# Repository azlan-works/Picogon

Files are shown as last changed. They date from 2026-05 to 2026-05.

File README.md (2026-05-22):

# Picogon
The Picogon in an opensource RP2354A based board for compact embedded applications. Designed as a host platform to integrate with more complex use cases, with peripherals attachable via exposed ENIG pads that connect to spring contacts on a compatible daughterboard. 

## Features:

- USB-C PD/PPS (3.3V to 24V)
- Battery management (3.7V LiPo)
- WiFi/BLE (2.4GHz built-in antenna)
- LoRa (SX1262 868-915MHz UFL connector)
- 9-axis DoF (IMU + Magnetometer)
- QWIIC/Stemma I2C port

  

  ## Notes:
  Currently untested

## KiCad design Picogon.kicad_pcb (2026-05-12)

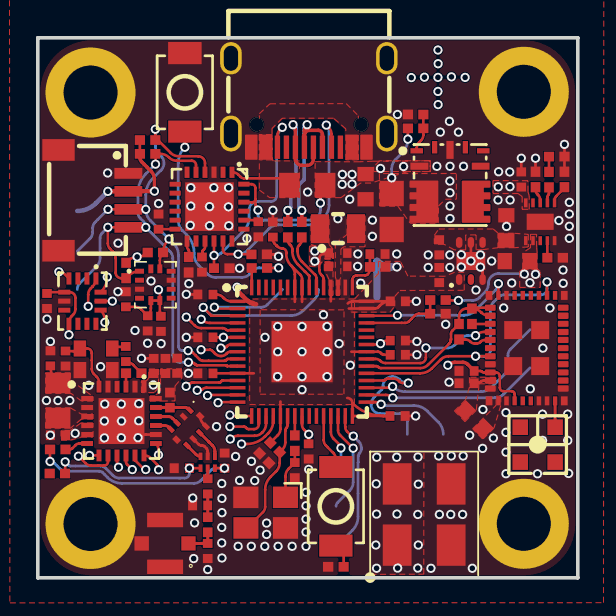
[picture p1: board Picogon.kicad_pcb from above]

Board: 6 copper layers, 30.0 x 30.0 mm, 100 parts (0 on the bottom side), 75 nets.

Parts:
AE1: 47948-0001; ANT-SMD_47948-0001
C1, C11, C21, C22: 4.7uF; C0402
C2, C3, C4, C5, C6, C7, C8, C9, C10, C26, C27, C29, C30, C31, C33, C36, C37: 100nF; C0402
C12, C13: 4.7uF; C0402_WIDE
C14, C15: 15pF; C0402
C16: 47uF; C0805
C17: 10uF; C0603
C18: 10uF; C0402
C19, C23: 22uF; C0603
C20, C24, C25, C28, C35: 1uF; C0402
C32: 10pF; C0402
C34: 470nF; C0402
C38: 47pF; C0402
C39: 39pF; C0402
C40, C41: 33pF; C0402
C42, C43: 3.9pF; C0402
CN1: QWIIC; CONN-SMD_4P-P1.00_SM04B-SRSS-TB-LF-SN
L1: 3.3uH; IND-SMD_L2.0-W1.6_AOTA-B201610S3R3-101-T
L2: 2.2uH; L0603
L3: 10uH; L0805
L4: 47nH; L0402
L5: 9.1nH; L0402
M1, M2, M3, M4: M3_Hole
M5: 0900FM15K0039001E; FILTER-SMD_10P-L2.0-W1.3-BL
R1: 33Ω; R0402
R2, R3, R6: 1kΩ; R0402
R4, R5: 27Ω; R0402
R7, R10, R13, R16, R17, R20, R21: 10kΩ; R0402
R8, R9, R26, R27: 4.7kΩ; R0402
R11: 470Ω; R0402
R12: 1.5kΩ; R0402
R14: 3.3kΩ; R0402
R15, R18: 220Ω; R0402
R19, R29: 100Ω; R0402
R22: 10mΩ; R0805
R23, R24: 5.1kΩ; R0402
R25: 10kΩ; R0402
R28: FM8625H; DFN-6_L1.1-W0.7-P0.40-BL
SW1, SW2: Button; SW-SMD_L3.9-W3.0-P4.45
TCXO1: 32MHz; OSC-SMD_4P-L2.0-W1.6-BL_1XXD
U1: RP2354A; QFN-60_L7.0-W7.0-P0.40-TL-EP3.4
U2: ABM8-272-T3; CRYSTAL-SMD_4P-L3.2-W2.5-BL
U3: TPSM84209RKHR; QFN-9_L4.5-W4.0_TPSM84209RKHR
U4: ICM-42688-P; LGA-14_L3.0-W2.5-P0.50-TL
U5: LBEE5KL1YN-814; LGA-46_L7.0-W5.2_LBEE5KL1DX-883
U6: BQ25185DLHR; WSON-10_L2.2-W2.0-P0.40-BL-EP_TI_DLH0010A
U7: TLV76733DRVR; WSON-6_L2.0-W2.0-P0.65-TL-EP
U8: AP33772DKZ-13; QFN-24_L4.0-W4.0-P0.50-TL-EP2.7
U9: LIS3MDLTR; LGA-12_L2.0-W2.0-P0.50-BL
U10: SX1262IMLTRT; QFN-24_L4.0-W4.0-P0.50-BL-EP2.6
U11: IPEX-1; IPEX-SMD_4P-L2.6-W2.6-LS3.0
U12: 009296002202906; CONN-SMD_009296002202906
USBC1: USB-C 16P; USB-C_SMD-TYPE-C-31-M-12_1

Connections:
+1V1: C1.2, C2.2, C3.2, C13.2, L1.2, U1.6 (DVDD), U1.23 (DVDD), U1.39 (DVDD), U1.50 (VREG_FB)
+3V3: C4.2, C5.2, C6.2, C7.2, C8.2, C9.2, C10.2, C12.2, C20.2, C21.2, C25.2, C29.2, C30.2, C31.2, C35.2, C36.2, CN1.2 (VCC), R1.1, R8.2, R9.2, R26.2, R27.2, U1.1 (IOVDD), U1.11 (IOVDD), U1.20 (IOVDD), U1.30 (IOVDD), U1.38 (IOVDD), U1.44 (ADC_AVDD), U1.45 (IOVDD), U1.49 (VREG_VIN), U1.53 (USB_OTP_VDD), U1.54 (QSPI_IOVDD), U4.5 (VDDIO), U4.8 (VDD), U5.30 (VBAT), U5.36 (VIO), U7.1 (OUT), U9.5 (Vdd), U9.6 (Vdd_IO), U10.1 (VDD_IN), U10.10 (VBAT), U10.11 (VBAT_IO)
+BATT: C23.2, R20.2, U6.2 (BAT), U12.1
/Power/BAT_ADC: R20.1, R21.2, U1.42 (GPIO28_ADC2)
/Power/CC1: R23.2, U8.17 (CC1), USBC1.A5 (CC1)
/Power/CC2: R24.2, U8.16 (CC2), USBC1.B5 (CC2)
/Power/D+: R4.2, USBC1.A6 (DP1), USBC1.B6 (DP2)
/Power/D-: R5.2, USBC1.A7 (DN1), USBC1.B7 (DN2)
/Power/PD_SCL: CN1.4 (SCL), R9.1, R27.1, U1.10 (GPIO7), U8.5 (SCL), U9.1 (SCL/SPC)
/Power/PD_SDA: CN1.3 (SDA), R8.1, R26.1, U1.9 (GPIO6), U8.4 (SDA), U9.11 (SDA/SDI/SDO)
/RP2354A/GPIO2: U1.4 (GPIO2), U4.13 (AP_SCL/AP_SCLK)
/RP2354A/GPIO3: U1.5 (GPIO3), U4.14 (AP_SDA/AP_SDIO/AP_SDI)
/RP2354A/GPIO4: U1.7 (GPIO4), U4.1 (AP_SDO/AP_AD0)
/RP2354A/GPIO5: U1.8 (GPIO5), U4.12 (AP_CS)
/RP2354A/GPIO8: U1.12 (GPIO8), U4.4 (INT1/INT)
/RP2354A/GPIO9: U1.13 (GPIO9), U10.19 (NSS)
/RP2354A/GPIO10: U1.14 (GPIO10), U10.18 (SCK)
/RP2354A/GPIO11: U1.15 (GPIO11), U10.17 (MOSI)
/RP2354A/GPIO12: U1.16 (GPIO12), U10.16 (MISO)
/RP2354A/GPIO13: U1.17 (GPIO13), U10.15 (NRESET)
/RP2354A/GPIO14: U1.18 (GPIO14), U10.13 (DIO1)
/RP2354A/GPIO15: U1.19 (GPIO15), U10.14 (BUSY)
/RP2354A/GPIO23: U1.35 (GPIO23), U5.14 (BT_REG_ON), U5.28 (WL_REG_ON)
/RP2354A/GPIO24: R10.2, R11.2, U1.36 (GPIO24), U5.22 (SDIO_CMD), U5.23 (SDIO_DATA_2)
/RP2354A/GPIO25: U1.37 (GPIO25), U5.25 (SDIO_DATA_3)
/RP2354A/GPIO29_ADC3: U1.43 (GPIO29_ADC3), U5.20 (SDIO_CLK)
/RP2354A/XIN: C15.1, U1.21 (XIN), U2.3
/RP2354A/XOUT: R2.2, U1.22 (XOUT)
/Wireless/DIO2: R19.1, U10.12 (DIO2)
/Wireless/DIO3: C33.2, TCXO1.4 (VCC), U10.6 (DIO3)
GND: C1.1, C2.1, C3.1, C4.1, C5.1, C6.1, C7.1, C8.1, C9.1, C10.1, C11.1, C12.1, C13.1, C14.2, C15.2, C16.1, C17.1, C18.1, C19.1, C20.1, C21.1, C22.1, C23.1, C24.1, C25.1, C26.1, C27.1, C28.1, C29.1, C30.1, C31.1, C33.1, C34.1, C35.1, C36.1, C37.1, C38.1, C40.2, C41.1, C42.1, C43.1, CN1.1 (GND), CN1.5, CN1.6, M1.1 (1_1), M2.1 (1_1), M3.1 (1_1), M4.1 (1_1), M5.2 (GND), M5.5 (GND), M5.7 (GND), M5.9 (GND), M5.10 (GND), R3.1, R12.1, R14.2, R15.2, R16.2, R17.1, R21.1, R23.1, R24.1, R25.1, R28.2 (GND), SW1.1, TCXO1.1 (GND), TCXO1.2 (GND), U1.47 (VREG_PGND), U1.61 (EP), U2.2 (GND), U2.4 (GND), U3.8 (GND), U4.6 (GND), U5.1 (GND), U5.12 (GND), U5.19 (GND), U5.21 (GND), U5.29 (GND), U5.32 (GND(SR_PVSS)), U5.33 (GND(SR_PVSS)), U5.35 (GND), U5.39 (BT_DEV_WAKE), U5.40 (GND), U5.42 (GND), U5.43 (GND), U5.44 (GND), U5.45 (GND), U5.46 (GND), U6.5 (GND), U6.11 (EP), U7.3 (GND), U7.5 (GND), U7.7 (EP), U8.3 (GND), U8.25 (EP), U9.3 (GND), U9.9 (SD0/SA1), U10.2 (GND), U10.5 (GND), U10.8 (GND), U10.20 (GND), U10.25 (GND), U11.1, U11.2, U11.3, U12.2, USBC1.1 (EH), USBC1.2 (EH), USBC1.3 (EH), USBC1.4 (EH), USBC1.A1B12 (GND), USBC1.B1A12 (GND)
unnamed: C14.1, R2.1, U2.1
unnamed: C32.2, R18.1
unnamed: C39.2, C42.2, L5.2
unnamed: M5.3 (RFI_N), U10.22 (RFI_N)
unnamed: M5.4 (RFI_P), U10.21 (RFI_P)
unnamed: L4.1, M5.1 (RFO/VR_PA), U10.23 (RFO)
unnamed: M5.6 (SW_RFI), R28.3 (RF1)
unnamed: M5.8 (SW_RFO), R28.1 (RF2)
unnamed: R3.2, SW2.1
unnamed: R6.1, SW1.2
unnamed: R13.2, R14.1
unnamed: C39.1, R28.5 (AND)
unnamed: C40.1, R19.2, R28.6 (VCTL)
unnamed: C41.2, R28.4 (VDD), R29.2
unnamed: C32.1, TCXO1.3 (Output)
unnamed: R6.2, U1.60 (QSPI_SS)
unnamed: SW2.2, U1.26 (RUN)
unnamed: R5.1, U1.51 (USB_DM)
unnamed: R4.1, U1.52 (USB_DP)
unnamed: C11.2, R1.2, U1.46 (VREG_AVDD)
unnamed: L1.1, U1.48 (VREG_LX)
unnamed: R7.2, R12.2, U3.1 (FB)
unnamed: AE1.3 (3_3), U5.41 (ANT)
unnamed: R11.1, U5.24 (SDIO_DATA_0)
unnamed: R10.1, U5.26 (SDIO_DATA_1)
unnamed: L2.2, U5.34 (SR_VLX)
unnamed: C22.2, L2.1, U5.31 (VIN_LDO)
unnamed: R13.1, U6.7 (ILIM/VSET)
unnamed: R15.1, U6.8 (ISET)
unnamed: R16.1, U6.6 (TS/MR)
unnamed: R17.2, U6.4 (~CE)
unnamed: C26.2, U8.15 (IFB)
unnamed: R25.2, U8.13 (OTP)
unnamed: C27.2, U8.12 (V3VD)
unnamed: C28.2, U8.20 (V5V)
unnamed: L3.1, U10.9 (DCC_SW)
unnamed: C34.2, L3.2, U10.7 (VREG)
unnamed: C37.2, C38.2, L4.2, U10.24 (VR_PA)
unnamed: R18.2, U10.3 (XTA)
unnamed: C43.2, L5.1, U11.4 (ANT)
VBUS: C17.2, R22.2, U3.2 (VIN), U8.22 (VBUS), U8.24 (VCC)
VBUS_C: R22.1, U8.1 (ISENP), USBC1.A4B9 (VBUS), USBC1.B4A9 (VBUS)
VCHG: C16.2, C18.2, R7.1, U3.3 (VOUT), U6.10 (IN)
VSYS: C19.2, C24.2, U6.1 (SYS), U7.4 (EN), U7.6 (IN)
